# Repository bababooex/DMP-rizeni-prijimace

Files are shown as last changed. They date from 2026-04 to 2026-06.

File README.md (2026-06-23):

# DMP-rizeni-prijimace
Program a schémata mé maturitní praktické práce. Některé návrhy DPS, popřípadě části programu se dají použít pro jiné účely. Vše slouží pro inspiraci a nemůžu nic garantovat. Knihovny by měly být použitelné i s jinými projekty s STM8S208RB a kompilátorem COSMIC.
# Co všechno program obsahuje?
- Kompletní knihovna na řízení digitálního potenciometru od Adafruitu - DS1841
- Kompletní knihovna na řízení kanálového voliče FM1216 (čip TSA5523)
- Kompletní knihovna na řízení kanálového modulátoru RMUP74055 (čip MBS74T1AEF)
- Kompletní knihovna na řízení satelitního kanálového voliče s čipem AV2026 (v mém programu nepoužito)
- Kompletní knihovna na řízení modulu hodin reálného času s čipem PCF8563
- Knihovna pro maticovou klávesnici s neblokujícím časovým ošetřením stisku
- Upravená knihovna pro 4x40 lcd display se dvěma jednotkami HD44780 (případně ekvivalenty)
- Knihovna pro zobrazení velkého fontu (dvouřádkového) pro lcd display (jenom čísla)
- Knihovna pro řízení rotačních enkodérů softwarově

A další spousta podpůrných knihoven určených specificky pro tento projekt (práce s pamětí, pásmo, vlastní znaky, přepínání režimů...) a samozřejmě hlavní program main
# Co je v KiCadu
- Úplné schéma zapojení hlavní DPS s tlačítkovou DPS, vlastní footprinty a kompletní návrhy obou DPS
# Vzhled
Vzhled sestaveného zařízení

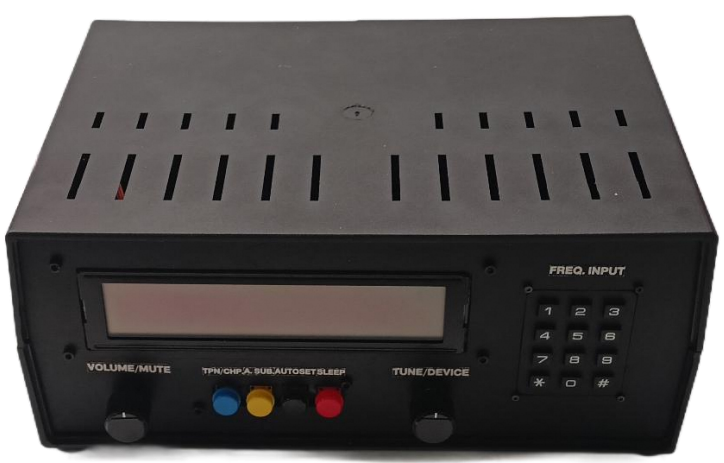
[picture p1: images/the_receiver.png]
the_receiver


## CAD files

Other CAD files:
Program/dlouhodobka.stp

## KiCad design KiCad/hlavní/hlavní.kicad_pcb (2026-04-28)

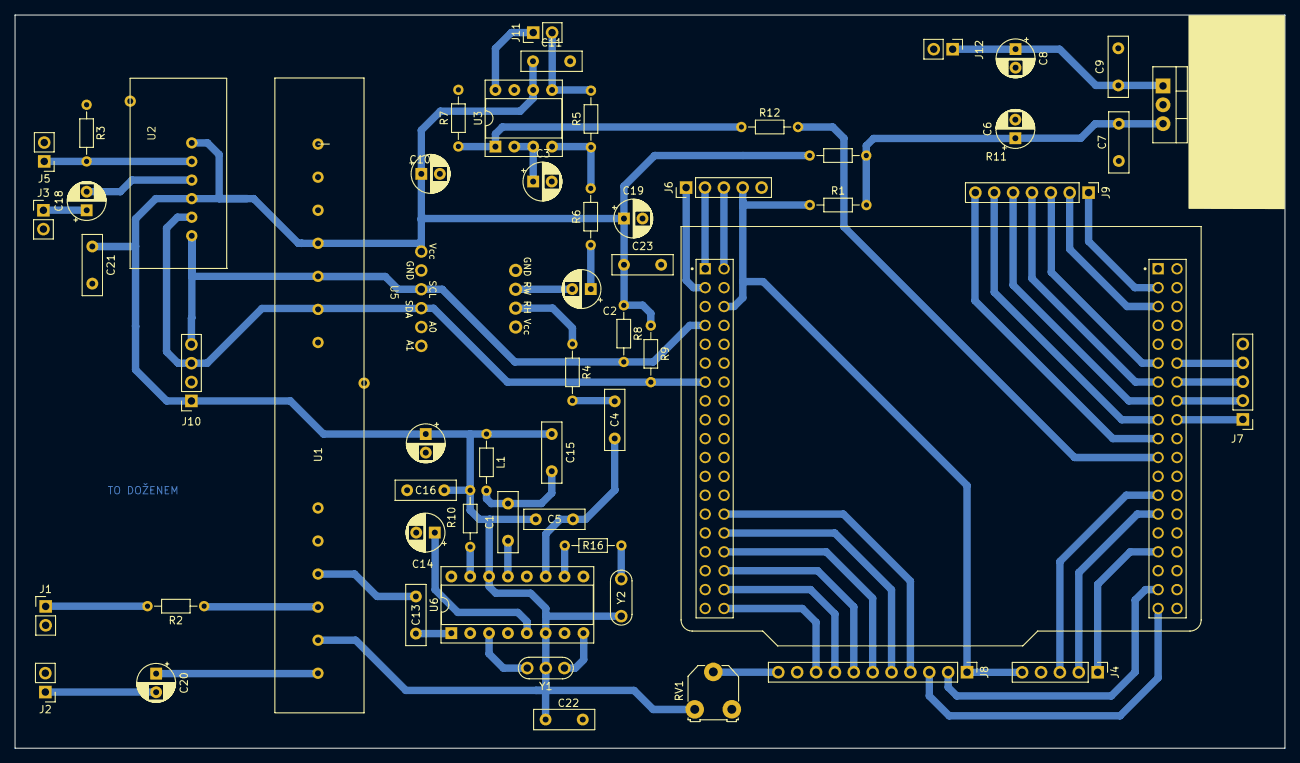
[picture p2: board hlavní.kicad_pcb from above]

Board: 2 copper layers, 170.9 x 98.7 mm, 58 parts (0 on the bottom side), 61 nets.

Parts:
C1: 15pF; C_Disc_D8.0mm_W2.5mm_P5.00mm
C2, C3, C10: 1uF; CP_Radial_D5.0mm_P2.50mm
C4, C7, C9, C11, C16, C21, C22, C23: 100nF; C_Disc_D8.0mm_W2.5mm_P5.00mm
C5: 10nF; C_Disc_D8.0mm_W2.5mm_P5.00mm
C6, C17: 100uF; CP_Radial_D5.0mm_P2.50mm
C8: 470uF; CP_Radial_D5.0mm_P2.50mm
C13: 1nF; C_Disc_D8.0mm_W2.5mm_P5.00mm
C14, C18, C20: 10uF; CP_Radial_D5.0mm_P2.50mm
C15: 20pF; C_Disc_D8.0mm_W2.5mm_P5.00mm
C19: 220uF; CP_Radial_D5.0mm_P2.50mm
J1: VIDEO OUT; PinHeader_1x02_P2.54mm_Vertical
J2: AUDIO OUT; PinHeader_1x02_P2.54mm_Vertical
J3: AUDIO IN; PinHeader_1x02_P2.54mm_Vertical
J4: Tuning; PinHeader_1x05_P2.54mm_Vertical
J5: VIDEO IN; PinHeader_1x02_P2.54mm_Vertical
J6: Volume; PinHeader_1x05_P2.54mm_Vertical
J7: Buttons; PinHeader_1x05_P2.54mm_Vertical
J8: LCD Display; PinHeader_1x11_P2.54mm_Vertical
J9: Matrix keypad; PinHeader_1x07_P2.54mm_Vertical
J10: RTC CLOCK; PinSocket_1x04_P2.54mm_Vertical
J11: FM OUT; PinHeader_1x02_P2.54mm_Vertical
J12: DC IN; PinHeader_1x02_P2.54mm_Vertical
L1: 2.2uH; R_Axial_DIN0204_L3.6mm_D1.6mm_P7.62mm_Horizontal
R1, R11: 0Ω; R_Axial_DIN0204_L3.6mm_D1.6mm_P7.62mm_Horizontal
R2, R16: 100Ω; R_Axial_DIN0204_L3.6mm_D1.6mm_P7.62mm_Horizontal
R3: 75Ω; R_Axial_DIN0204_L3.6mm_D1.6mm_P7.62mm_Horizontal
R4: 47kΩ; R_Axial_DIN0204_L3.6mm_D1.6mm_P7.62mm_Horizontal
R5: 27kΩ; R_Axial_DIN0204_L3.6mm_D1.6mm_P7.62mm_Horizontal
R6: 10kΩ; R_Axial_DIN0204_L3.6mm_D1.6mm_P7.62mm_Horizontal
R7: 100kΩ; R_Axial_DIN0204_L3.6mm_D1.6mm_P7.62mm_Horizontal
R8, R9: 2.2kΩ; R_Axial_DIN0204_L3.6mm_D1.6mm_P7.62mm_Horizontal
R10: 1kΩ; R_Axial_DIN0204_L3.6mm_D1.6mm_P7.62mm_Horizontal
R12: 330Ω; R_Axial_DIN0204_L3.6mm_D1.6mm_P7.62mm_Horizontal
RV1: 5kΩ; TRIMPOT_ROUND
U1: TSA5523
U2: MBS74T1AEF
U3: 8002; DIP-8_W7.62mm_Socket
U4: STM8S208-NUCLEO; ST_NUCLEO-F303RE
U5: ds1841
U6: CD2003GB_GP; DIP-16_W7.62mm_Socket
U7: L7805; LM7805
Y1: 10.7MHz; Resonator-3Pin_W7.0mm_H2.5mm
Y2: 10.7MHz; Resonator-2Pin_W7.0mm_H2.5mm

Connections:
GND: C3.2, C6.2, C7.2, C8.2, C9.2, C10.2, C11.2, C14.2, C16.2, C17.2, C19.2, C21.2, C22.2, C23.2, J1.2, J2.2, J3.2, J4.4, J5.2, J6.5, J7.5, J8.10, J10.2, J12.2, R3.1, R7.2, RV1.1, U1.14 (GND), U2.7 (GND), U3.7 (GND), U4.5 (NC), U4.6 (NC), U4.10 (GND), U4.11 (NC), U4.28 (GND), U4.29 (GND), U4.34 (NC), U4.35 (GND), U4.43 (GND), U4.67 (GND), U5.1 (GND), U6.2 (GND_IN), U6.9 (GND_OUT), U7.2 (GND)
unnamed: C1.2, C15.2, L1.2
unnamed: C2.1, R6.1
unnamed: C4.2, R4.2
unnamed: J1.1, R2.2
unnamed: C20.2, J2.1
unnamed: C18.1, J3.1
unnamed: J4.1, U4.54 (PC1)
unnamed: J4.2, U4.52 (PC2)
unnamed: J4.3, U4.51 (PC3)
unnamed: J4.5, J6.4, J8.1, R1.1, U4.36 (E5V)
unnamed: J5.1, R3.2, U2.2 (VID)
unnamed: J6.1, U4.2 (PG5)
unnamed: J6.2, U4.1 (PG4)
unnamed: J6.3, U4.38 (PG7)
unnamed: J7.1, U4.68 (PF3)
unnamed: J7.2, U4.69 (PF4)
unnamed: J7.3, U4.70 (PF5)
unnamed: J7.4, U4.71 (PF6)
unnamed: J8.2, U4.56 (PD5)
unnamed: J8.3, U4.57 (PD6)
unnamed: J8.4, U4.25 (PB5)
unnamed: J8.5, U4.24 (PB4)
unnamed: J8.6, U4.23 (PB3)
unnamed: J8.7, U4.22 (PB2)
unnamed: J8.8, U4.21 (PB1)
unnamed: J8.9, U4.20 (PB0)
unnamed: J8.11, RV1.2
unnamed: J9.1, U4.40 (PE1)
unnamed: J9.2, U4.41 (PE2)
unnamed: J9.3, U4.44 (PC5)
unnamed: J9.4, U4.45 (PC7)
unnamed: J9.5, U4.46 (PC6)
unnamed: J9.6, U4.47 (PE5)
unnamed: J9.7, U4.48 (PC4)
unnamed: C5.2, C10.1, C11.1, C15.1, C16.1, C17.1, C19.1, C21.1, C22.1, C23.1, J10.1, L1.1, R8.1, R9.1, R10.2, R11.1, RV1.3, U1.4 (+BT), U1.12 (+BD), U2.1 (BB), U2.4 (MB), U3.6 (VDD), U5.4 (Vcc), U6.6 (VCC), U6.14 (FM/AM_SW), Y1.2, Y2.1
unnamed: J10.3, R9.2, U1.6 (SDA), U2.5 (SDA), U4.7 (PE6), U5.8 (SDA)
unnamed: J10.4, R8.2, U1.5 (SCL), U2.6 (SCL), U4.4 (PE7), U5.7 (SCL)
unnamed: J11.1, U3.8 (V02)
unnamed: J11.2, R5.2, U3.5 (V01)
unnamed: C8.1, C9.1, J12.1, U7.1 (IN)
unnamed: R16.1, Y2.2
unnamed: C20.1, U1.13 (AF)
unnamed: R2.1, U1.11 (CVBS)
unnamed: C13.2, U1.10 (MPX)
unnamed: C18.2, U2.3 (AUD)
unnamed: C3.1, U3.2 (BYP), U3.3 (+IN)
unnamed: R5.1, R6.2, U3.4 (-IN)
unnamed: R7.1, R12.1, U3.1 (SD)
unnamed: R12.2, U4.49 (PD3)
unnamed: R4.1, U5.3 (RH)
unnamed: C2.2, U5.2 (RW)
unnamed: C14.1, U6.5 (AGC)
unnamed: C4.1, C5.1, U6.11 (DET_OUT)
unnamed: R16.2, U6.10 (FM_DET)
unnamed: U6.8 (FM_IF), Y1.1
unnamed: U6.3 (FM_MIX), Y1.3
unnamed: C1.1, U6.13 (FM_OSC)
unnamed: C13.1, U6.1 (FM_RF_IN)
unnamed: R10.1, U6.15 (FM_TUNER)
unnamed: C6.1, C7.1, R1.2, R11.2, U7.3 (OUT)

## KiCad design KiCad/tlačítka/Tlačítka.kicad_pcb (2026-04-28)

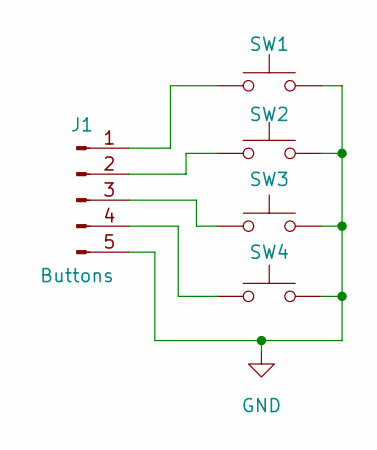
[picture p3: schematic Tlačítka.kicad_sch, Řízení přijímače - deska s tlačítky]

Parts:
J1: Buttons; PinSocket_1x05_P2.54mm_Vertical
SW1, SW2, SW3, SW4: SW_Push; SW_PUSH-12mm

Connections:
GND: J1.5, SW1.2, SW2.2, SW3.2, SW4.2
unnamed: J1.1, SW1.1
unnamed: J1.2, SW2.1
unnamed: J1.3, SW3.1
unnamed: J1.4, SW4.1

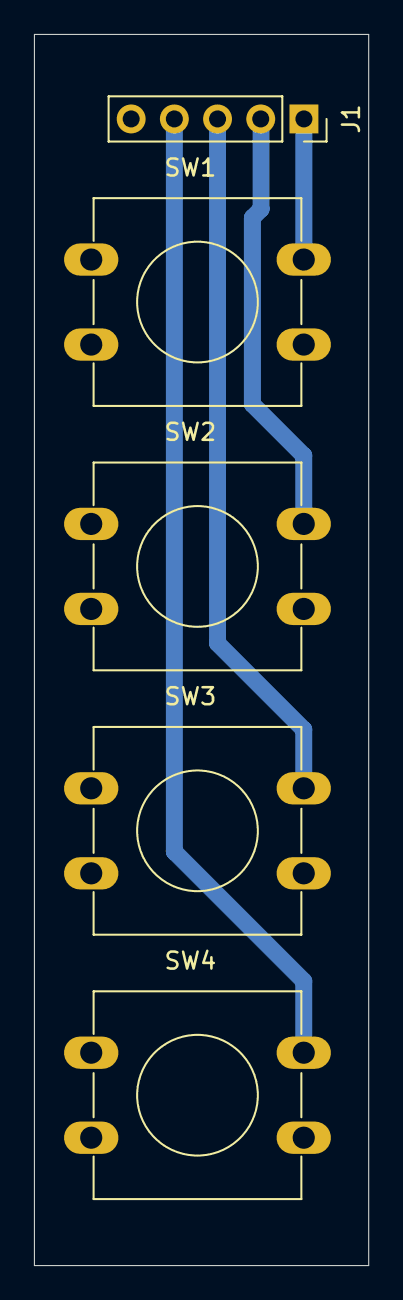
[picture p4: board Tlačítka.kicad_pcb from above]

Board: 2 copper layers, 19.7 x 72.4 mm, 5 parts (0 on the bottom side), 5 nets.

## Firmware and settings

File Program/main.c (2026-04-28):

/*
 * File:  main.c
 * Date:   4.11.2025 18.47
 * Author:  Adam Fucik   https://github.com/bababooex
 * Licence: GNU/GPL 
 * Task: Receiver with TV tuner and transmitter with rf modulator -> TV transceiver 
 * Description: Main file for controlling tv tuner and rf modulator, needs all library files to work correctly!
 ****************************************************/
 /* lil bit of ascii art
				o                   o
				\               __/
				 \___          /
						 \__    __/
								\  /
		 ____________\/____________
		/   ____________________   \
		|  /__/  \__   \__/  \__\  |
		| |    __   \__    __   \| |
		| |\__/  \__   \__/  \__ | |
		| |    __   \__    __   \| |
		| |\__/  \__   \__/  \__ | |
		| |    __   \__    __   \| |
		| |\__/  \__   \__/  \__ | |
		| |    __   \__    __   \| |
		| |\__/  \__   \__/  \__ | |
		|  \________\___________/  |
		|                 _   _    |
		|  prs           (|) (/)   |
		\_________________________/
				"--"           "--"
 */
 
//all defines, that directly modify, how code behaves
#define SHOW_GUIDE //show guide and copyright
//#define DEBUG //for debugging over swuart 
//#define RTC_SET //set rtc clock time, so it is correct, after that, it should not be defined again
//#define EXPERIMENTAL_MODE //enables experimental mode for rf modulator, only used it specific situations
//#define FM_MODE //Only if required, or if tuner supports it, for FMR and FML outputs, not used in my code

//standard C libraries for stm8
#include "stm8s.h"
#include <stdbool.h>
#include <stdio.h>
#include <stdlib.h>
#include <string.h>

//all display and other important libraries
#include "off_handler.h"
#include "user_input.h"//input logic library
#include "guide.h"//library for guide
#include "stm8s_tim4.h"//tim4
#include "swuart.h"//software uart for debugging
#include "stm8_hd44780.h"//lcd library
#include "bigfont.h"//bigfont library
#include "stm8s_delay.h"//delay library
#include "audio.h"//handling sound 
#include "band.h"//band info
#include "rxtx.h"//decimal dot and CH
#include "rotary_encoder.h"// handle otary encoder movement
#include "disp_perks.h"//display custom chars
#include "keypad.h"//keypad handling library
#include "extern_variables.h"//all extern variables for all libraries
#include "stat_and_conf.h"//status and config bits
#include "autoset.h"//autoset tuner or modulator
#include "freq_and_ch_handler.h"//handle channel or frequency display and movement
#include "memory.h"//memory save library

//all custom device libraries
#include "mbs74t1aef.h"//modulator 
#include "tsa5523.h"//tuner
#include "pcf8563.h"//rtc clock
#include "ds1841.h" //doesnt need to be here, but nice for working with its functions
//#include "av2026.h" //for future frequenc
//for interrupt
uint16_t tim4_ms_counter;
bool rtc_update_flag;
uint32_t system_ms; // dont have to reset it, it would run for 49 days fine
uint8_t tim4_s_counter; //for seconds
uint8_t status_counter; // for periodically updating status
#define ENCODER_STOP_MS 2000 //prevent encoder movement when switching between modes, avoids unresolvable problems

//debugging routine
uint8_t *data; // pointer for printing data on lcd


//status change flags, to avoid noise etc.
bool audio_changed = false;
uint8_t new_wiper_value = 0;
bool update_status = false;
bool channel_changed = false;
bool frequency_changed = false;

//main mode logic, typedef is in extern variables
void tuner_loop(void); //tuner handling
void modulator_loop(void); //modulator handling
DeviceMode currentMode = MODE_RX; //start receiver
bool modeChanged = false; //checking switch

bool tuner_start=true;//start modes for initialization
bool mod_start=true;//start modes for initialization

// buttons - from encoders and for other functions
#define MODE_PIN GPIOC, GPIO_PIN_3//encoder1
#define MUTE_PIN GPIOG, GPIO_PIN_5//encoder2

#define MUTE_OUT_PIN GPIOD, GPIO_PIN_3//for mute function of amp
//buttons for additional functions
#define BTN4_PIN GPIOF, GPIO_PIN_3
#define BTN3_PIN GPIOF, GPIO_PIN_4
#define BTN2_PIN GPIOF, GPIO_PIN_5
#define BTN1_PIN GPIOF, GPIO_PIN_6

/*
//multiplexer pins, not really used in here
#define MUX_C GPIOB, GPIO_PIN_7 // for AF output (also FM/TV mode)
#define MUX_B GPIOB, GPIO_PIN_6 // FM/TV MODE HW audio switch
#define MUX_A GPIOD, GPIO_PIN_4 // HW mute function
*/

//frequency and channel variables
float frec;
int8_t frec2;
uint16_t frec1;
uint8_t channel; 
//old test code thingies
//rfmod_sound_system sound;
//bool input_mode = false;

//struct for time -> refer to PCF8563 library
struct {
    unsigned char s;
    unsigned char m;
    unsigned char h;
    unsigned char dy;
    unsigned char dt;
    unsigned char mt;
    unsigned char yr;
} time;
//other handlers and setups
void clock_setup(void); //handle correct clock config and pheripheral setting
void mode_choice(void); //arrow pointer function on lcd
void TIM4_setup(void); //tim4 for handling interrupt
void I2C_Handler(void); //handle i2c communication - low noise option

void main(void) {
	clock_setup();
	lcd_init();
	#ifdef SHOW_GUIDE
	GPIO_Init(BTN1_PIN, GPIO_MODE_IN_PU_NO_IT);
	GPIO_Init(MUTE_OUT_PIN, GPIO_MODE_OUT_PP_LOW_SLOW);
	GPIO_WriteHigh(MUTE_OUT_PIN);
	display_guide();//display guide
	while (1) {
	if (GPIO_ReadInputPin(BTN1_PIN) == RESET) {
			      lcd_gotoxy(0,3);
						lcd_puts("Going to receiver mode...     ");
					  delay_ms(2000);
						lcd_select(LCD_CTRL1);
						lcd_clear();
						lcd_select(LCD_CTRL2);
						lcd_clear();
						break;
			}
	}
	#endif
	#ifdef DEBUG
   uart_init();
	#endif
	TIM4_setup();//for nonblocking time
	enableInterrupts();//enabling interrupts globally
	swi2c_init();//enable swi2c
	//INIT clock functions for setting time, if time set, just dont use them
	#ifdef RTC_SET
	PCF8563_init();//put rtc into write mode
  custom_time(); //set custom clock time
	#endif

	lcd_select(LCD_CTRL2);
	bigfont_init();
	perks_show();
	Band_init();
	s_a_c_init();
	AUD_blank();
	#ifndef SHOW_GUIDE //prevent reinit, if show guide
	GPIO_Init(MUTE_OUT_PIN, GPIO_MODE_OUT_PP_LOW_SLOW);
	GPIO_WriteHigh(MUTE_OUT_PIN);
	#endif
	rxtx_show();
	keypad_init();
	Encoder_Init(ENCODER1);
	Encoder_Init(ENCODER2);
	GPIO_Init(MODE_PIN, GPIO_MODE_IN_PU_NO_IT);
	#ifndef SHOW_GUIDE //prevent reinit, if show guide
	GPIO_Init(BTN1_PIN, GPIO_MODE_IN_PU_NO_IT);
	#endif
	GPIO_Init(BTN2_PIN, GPIO_MODE_IN_PU_NO_IT);
	GPIO_Init(BTN3_PIN, GPIO_MODE_IN_PU_NO_IT);
	GPIO_Init(BTN4_PIN, GPIO_MODE_IN_PU_NO_IT);
	while (1) { //main switching choice logic -> The magic and the mystery of this program (potato knishes)
        switch (currentMode) {
            case MODE_RX:
                tuner_loop();
                break;
            case MODE_TX:
                modulator_loop();
                break;
        }
    }
}
void clock_setup(void)
	{
		//setup clock for 16 MHz
    CLK_DeInit();
    CLK_HSECmd(DISABLE);
    CLK_LSICmd(DISABLE);
    CLK_HSICmd(ENABLE);
    while (CLK_GetFlagStatus(CLK_FLAG_HSIRDY) == FALSE);
    CLK_ClockSwitchCmd(ENABLE);
    CLK_HSIPrescalerConfig(CLK_PRESCALER_HSIDIV1);
    CLK_SYSCLKConfig(CLK_PRESCALER_CPUDIV1);
    CLK_ClockSwitchConfig(CLK_SWITCHMODE_AUTO, CLK_SOURCE_HSI,
                          DISABLE, CLK_CURRENTCLOCKSTATE_ENABLE);
    CLK_PeripheralClockConfig(CLK_PERIPHERAL_I2C, DISABLE); //using swi2c not hw
		CLK_PeripheralClockConfig(CLK_PERIPHERAL_SPI, DISABLE);
		CLK_PeripheralClockConfig(CLK_PERIPHERAL_ADC, DISABLE);
		CLK_PeripheralClockConfig(CLK_PERIPHERAL_AWU, DISABLE);
		CLK_PeripheralClockConfig(CLK_PERIPHERAL_UART1, DISABLE); //using swuart not hw
		CLK_PeripheralClockConfig(CLK_PERIPHERAL_TIMER1, DISABLE);
		CLK_PeripheralClockConfig(CLK_PERIPHERAL_TIMER2, DISABLE);
		//CLK_PeripheralClockConfig(CLK_PERIPHERAL_TIMER3, DISABLE); swuart handles this
		CLK_PeripheralClockConfig(CLK_PERIPHERAL_TIMER4, ENABLE);//enable tim4 for interupts
  }
void mode_choice(void){//show arrow at current mode
	if (currentMode == MODE_RX){
		 lcd_gotoxy(13,1);
	   lcd_data(0xF7);
	   lcd_gotoxy(14,1);
	   lcd_data(0x3D);
   }
	else if (currentMode == MODE_TX){
		 lcd_gotoxy(13,1);
	   lcd_data(0x3D);
	   lcd_gotoxy(14,1);
	   lcd_data(0xF6);
	 }
}
//handling interrupt timer and flags
void TIM4_setup(void)
{
    TIM4_DeInit();
    TIM4_TimeBaseInit(TIM4_PRESCALER_128, 125-1);//1ms clock
    TIM4_ITConfig(TIM4_IT_UPDATE, ENABLE);
    TIM4_Cmd(ENABLE);
}


// tuner loop mechanism
void tuner_loop(void) {
	  flag_handler();
	  #ifdef DEBUG //debugging via uart
		  data = "Tuner initialised\r\n";
      uart_send_string(data);
	  #endif
		modeChanged = false;
		mode_choice();
		if (tuner_start == 1) {
						mod_display_chan(channel, true);
					  AUD_mute();
		}
		else{
			c_update();
			s_update();//update status
		}
		
    while (!modeChanged) {
				if (GPIO_ReadInputPin(MODE_PIN) == RESET) {
						system_ms = 0; //reset and compare
            modeChanged = true;
            currentMode = MODE_TX;
						delay_ms(600);
						continue;
        }
				if (GPIO_ReadInputPin(BTN4_PIN) == RESET) {
					  delay_ms(300);
						tuner_toggle_off();
						#ifdef DEBUG
						data = "Tuner OFF\r\n";
						uart_send_string(data);
						#endif
        }
				if (tun_off) {
					  s_a_c_init(); //serves as off mode also
            tuner_display_off();
            flag_handler();
            continue; //skip other stuff
        }
				
			  input_handler();
				flag_handler();

				if (GPIO_ReadInputPin(BTN1_PIN) == RESET) {
					  delay_ms(300);
				    c_toggleCP();
        }

				if (GPIO_ReadInputPin(BTN3_PIN) == RESET) {
					if (mod_off==1 || mod_start==1) {
            continue; //skip other stuff
					}
					else{
					 autoset_Modulator();
					 delay_ms(300);
					 mod_display_chan(channel, mod_off);
					 rfmod_changeChannel(channel, tpen_enabled);
				  }
        }

			  if (GPIO_ReadInputPin(MUTE_PIN) == RESET) {
					  delay_ms(300);
						AUD_mute();//simply mute audio if not wanted
				}
        if (GPIO_ReadInputPin(MODE_PIN) == RESET) {
            modeChanged = true;
            currentMode = MODE_TX;
						delay_ms(600);
        }
				if (update_status){
								s_update();
								update_status=0;
				}
				AUD_update();
				I2C_Handler();
				if (system_ms >= ENCODER_STOP_MS){
						update_tuner_freq();
				}
    }
}
//modulator loop mechanism
void modulator_loop(void) {
    flag_handler();

    #ifdef DEBUG
        data = "Modulator initialised\r\n";
        uart_send_string(data);
    #endif
		modeChanged = false;
    mode_choice();

    if (mod_start == 1) {
        s_a_c_init();	  
    }
		else{
			c_update();
			s_update();//update status
		}
    while (!modeChanged) {
        if (!experimental_mode && GPIO_ReadInputPin(MODE_PIN) == RESET) {
						system_ms = 0; //reset and compare
            modeChanged = true;
            currentMode = MODE_RX;
            delay_ms(600);
            continue;
        }


        if (!experimental_mode && GPIO_ReadInputPin(BTN4_PIN) == RESET) {
            delay_ms(300);
            mod_toggle_off();
						#ifdef DEBUG
						data = "Modulator OFF\r\n";
						uart_send_string(data);
						#endif
        }

        if (mod_off) {
            s_a_c_init();
            mod_display_off();
            flag_handler();
            continue;
        }

        input_handler();
        flag_handler();


        if (GPIO_ReadInputPin(BTN2_PIN) == RESET) {
            delay_ms(300);
            c_toggleAUDIO();
        }

        if (!experimental_mode && GPIO_ReadInputPin(BTN1_PIN) == RESET) {
            delay_ms(300);
            c_toggleTPEN();
        }


        if (!experimental_mode && GPIO_ReadInputPin(BTN3_PIN) == RESET) {
            if (!tun_off) {
                autoset_Tuner();
                delay_ms(300);
                tuner_display_frequency(frec1, frec2, tun_off);
                tuner_setFrequency(frec);
            }
        }


				if (GPIO_ReadInputPin(MUTE_PIN) == RESET) {
                delay_ms(300);
                AUD_mute();
				}
				if (!tun_off) {
                AUD_update();
				}
				if (update_status){
								s_update();
								update_status=0;
				}
				I2C_Handler();
				if (!experimental_mode || system_ms >= ENCODER_STOP_MS){
						update_mod_chan();
			  }
    }
}

void I2C_Handler(void)//i2c handling separately, because of noise and basically useless i2c communication
{
    if (audio_changed) {
        DS1841_setWiper(new_wiper_value);
        audio_changed = false;
    }
		else if (currentMode == MODE_TX && channel_changed){
				s_update();
				channel_changed = false;
			}
		else if (currentMode == MODE_RX && frequency_changed){
			  s_update();
				Band_update();
				if (frec>=460.0 && frec<=470.0){//fix bug with receiver symbol
					rxtx_fix();
				}
				frequency_changed = false;
			}
}
//----------------------ASSERT-----------------------
#ifdef USE_FULL_ASSERT

/**
  * @brief  Reports the name of the source file and the source line number
  *   where the assert_param error has occurred.
  * @param file: pointer to the source file name
  * @param line: assert_param error line source number
  * @retval : None
  */
void assert_failed(u8* file, u32 line)
{ 
  /* User can add his own implementation to report the file name and line number,
     ex: printf("Wrong parameters value: file %s on line %d\r\n", file, line) */

  /* Infinite loop */
  while (1)
  {
  }
}
#endif

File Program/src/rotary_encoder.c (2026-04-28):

#include "rotary_encoder.h"

static int16_t enc1_delta = 0;
int16_t encoder2_counter; 
int16_t encoder1_counter;

//limits based on encoder steps
#define UPPER_LIMIT 12
#define LOWER_LIMIT 0

int16_t Encoder1_GetDelta(void)//fixes problems with sharing encoder
{
    int16_t delta;
		delta = encoder1_counter;//basically comparing difference for each device, so it should be good
    encoder1_counter = 0;
    return delta;
}
//init, in my application, it could be both at the same time, but whatever
void Encoder_Init(EncoderId id)
{
    switch(id)
    {
        case ENCODER1:
						GPIO_Init(ENC1_PORT, ENC1_A_PIN | ENC1_B_PIN, GPIO_MODE_IN_PU_NO_IT);
						
            break;
        case ENCODER2:
            GPIO_Init(ENC2_PORT, ENC2_A_PIN | ENC2_B_PIN, GPIO_MODE_IN_PU_NO_IT);
						
            break;
    }
}
//encoder for two modes
void Encoder1_Update(void) {
    uint8_t currentState = 0;
		static uint8_t lastState = 0;			
    delay_us(100);

    if (GPIO_ReadInputPin(ENC1_PORT, ENC1_A_PIN)) currentState |= 0x01;
    if (GPIO_ReadInputPin(ENC1_PORT, ENC1_B_PIN)) currentState |= 0x02;
		//stupid, but works
    //clockwise rotation
    if ((lastState == 0x00 && currentState == 0x01) ||
        (lastState == 0x01 && currentState == 0x03) ||
        (lastState == 0x03 && currentState == 0x02) ||
        (lastState == 0x02 && currentState == 0x00)) {
        encoder1_counter--;
    }
    //counter-clockwise rotation
    else if ((lastState == 0x00 && currentState == 0x02) ||
             (lastState == 0x02 && currentState == 0x03) ||
             (lastState == 0x03 && currentState == 0x01) ||
             (lastState == 0x01 && currentState == 0x00)) {
        encoder1_counter++;
    }
		
    lastState = currentState;
}
//encoder for audio
//tim1 updates automatically, but sw requires polling or interrupt
void Encoder2_Update(void) {
    static uint8_t lastState = 0; 
    uint8_t currentState = 0;
					
    delay_us(100);

    if (GPIO_ReadInputPin(ENC2_PORT, ENC2_A_PIN)) currentState |= 0x01;
    if (GPIO_ReadInputPin(ENC2_PORT, ENC2_B_PIN)) currentState |= 0x02;
		
    //clockwise rotation
    if ((lastState == 0x00 && currentState == 0x01) ||
        (lastState == 0x01 && currentState == 0x03) ||
        (lastState == 0x03 && currentState == 0x02) ||
        (lastState == 0x02 && currentState == 0x00)) {
        encoder2_counter--;
    }
    //counter-clockwise rotation
    else if ((lastState == 0x00 && currentState == 0x02) ||
             (lastState == 0x02 && currentState == 0x03) ||
             (lastState == 0x03 && currentState == 0x01) ||
             (lastState == 0x01 && currentState == 0x00)) {
        encoder2_counter++;
    }
		
    lastState = currentState;
		//prevent overflow
		if (encoder2_counter>UPPER_LIMIT){
				encoder2_counter=UPPER_LIMIT;
		}
		else if (encoder2_counter<LOWER_LIMIT){
				encoder2_counter=LOWER_LIMIT;
		}
}
//getting encoder values
int16_t Encoder_GetValue(EncoderId id)
{
    if (id == ENCODER1) {
			  return encoder1_counter;
    } else {
        return encoder2_counter;
    }
}

//encoder reset
void Encoder_Reset(EncoderId id)
{
    if (id == ENCODER1)
				encoder1_counter = 0;
    else
        encoder2_counter = 0;
}

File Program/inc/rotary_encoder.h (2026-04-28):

#ifndef ROTARY_ENCODER_H
#define ROTARY_ENCODER_H
#include "stm8s.h"
#include "stm8s_delay.h"
#include "extern_variables.h"
//encoder choice based on movement
typedef enum {
    ENCODER1 = 0,   
    ENCODER2        
} EncoderId;
//for second encoder
#define ENC2_A_PIN   GPIO_PIN_7
#define ENC2_B_PIN   GPIO_PIN_4
#define ENC2_PORT    GPIOG

#define ENC1_A_PIN   GPIO_PIN_1
#define ENC1_B_PIN   GPIO_PIN_2
#define ENC1_PORT    GPIOC

/**
 * @brief functions regarding this sw/hw rotary encoder control
 * - init encoder tim handler
 * - get value of rotary encoder
 * - reset rotary encoder value (debug etc.)
 */
void Encoder_Init(EncoderId id);
int16_t Encoder_GetValue(EncoderId id); //basic getter function, that gets two counters, only used for audio in this instance
int16_t Encoder1_GetDelta(void); //new function, that is made to work with two modes, each handles difference separatelly
void Encoder_Reset(EncoderId id);
void Encoder2_Update(void);
void Encoder1_Update(void);
#endif // ROTARY_ENCODER_H
